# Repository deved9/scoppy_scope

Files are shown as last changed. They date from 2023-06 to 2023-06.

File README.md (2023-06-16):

# scoppy scope

scoppy_scope is a project of mine, where i try to fit a custom small form-factor 2 channel osciloscope to a Thinkpad T430's smart card reader bay.

Project is currently in development, the frontend is tested to be fully working without the use of the range switching IC. 

This project was inspired by the [Scoppy oscilloscope and logic analyzer project](https://github.com/fhdm-dev/scoppy) which sadly only supports Android devices as of this date. 

The digital part of the project, including part of the schematic and footprints, has been taken from the [Adafruit QT Py RP2040](https://github.com/adafruit/Adafruit-QT-Py-RP2040-PCB)

As of right now, the PCB is close to finished. The main focus will be shifted to the software side of the project.

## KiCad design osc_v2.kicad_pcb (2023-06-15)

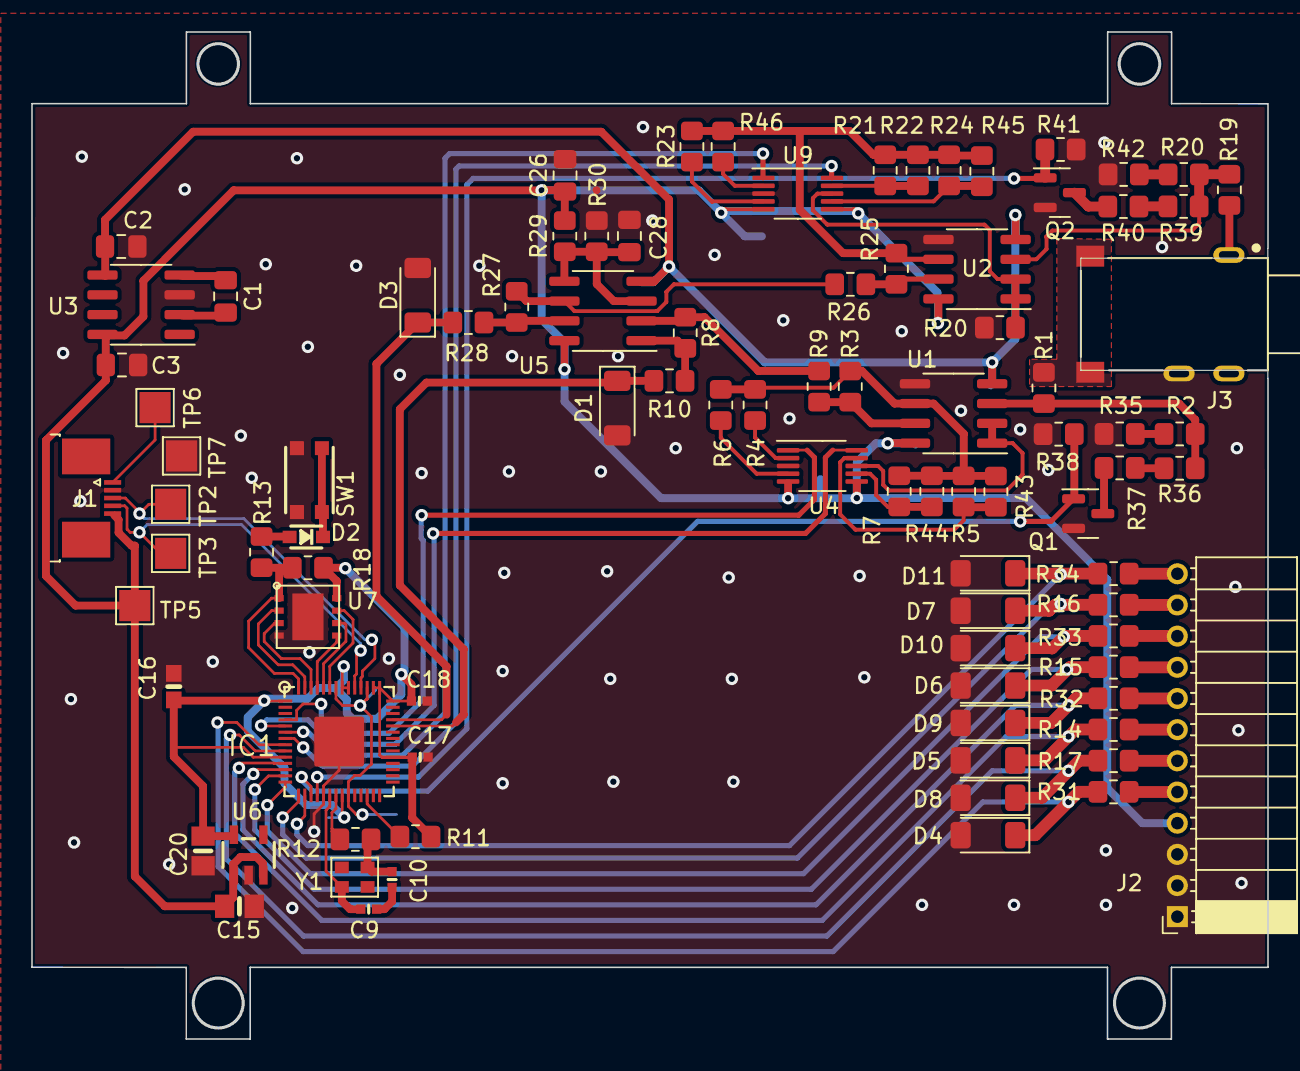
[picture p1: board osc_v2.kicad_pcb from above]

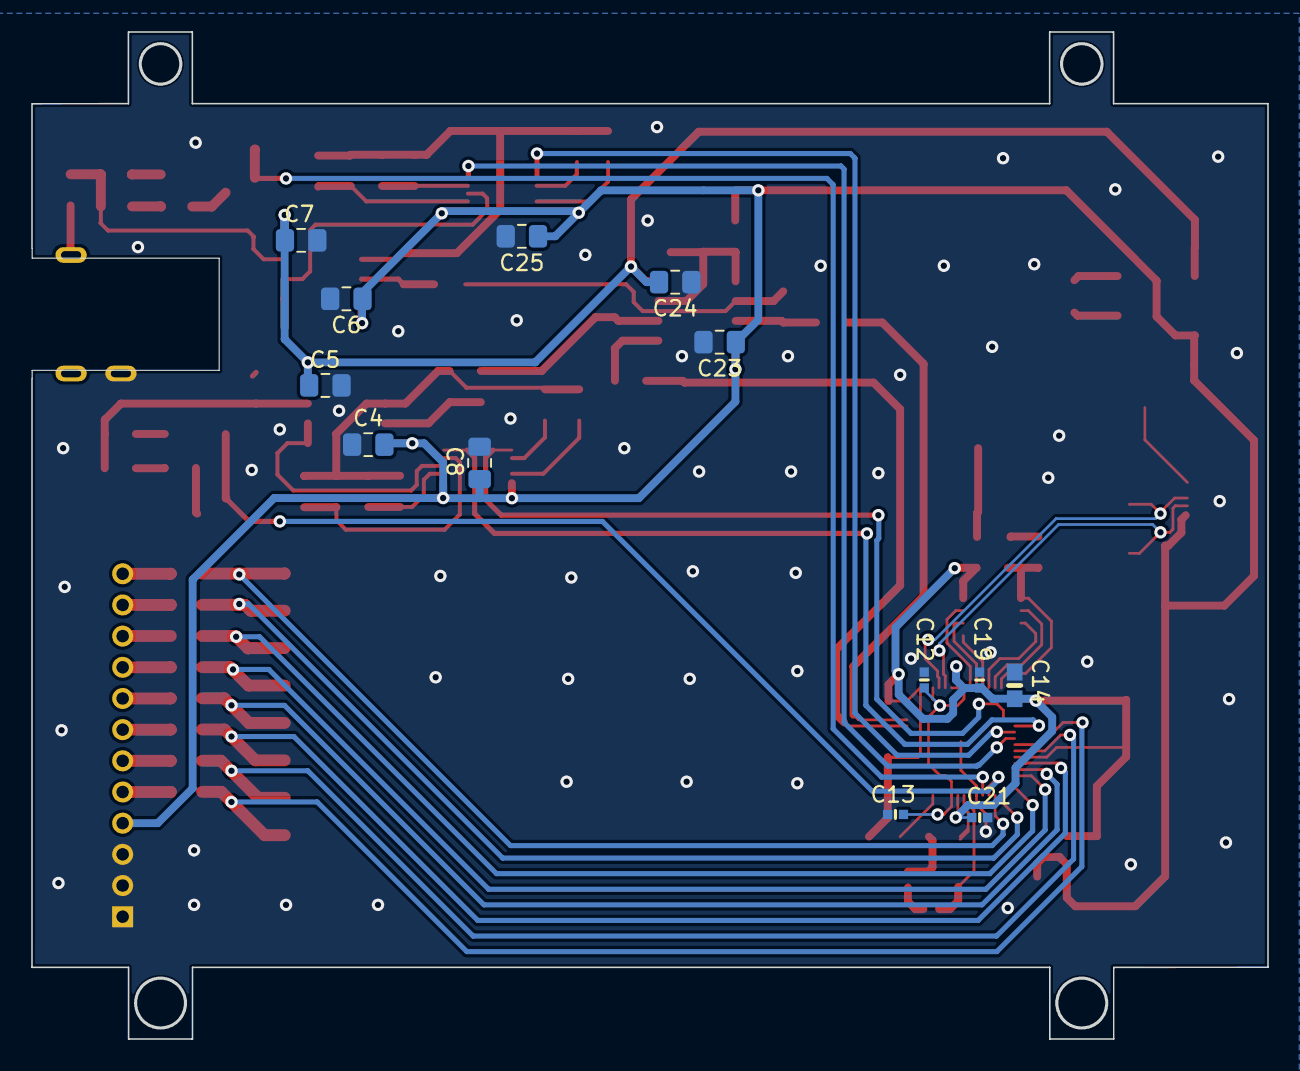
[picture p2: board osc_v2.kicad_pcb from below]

Board: 2 copper layers, 79.3 x 64.6 mm, 104 parts (13 on the bottom side), 76 nets.

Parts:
C1: 10u; C_0805_2012Metric_Pad1.18x1.45mm_HandSolder
C2, C3, C4, C5, C6, C7, C8, C23, C24, C25, C26, C28: 100u; C_0805_2012Metric_Pad1.18x1.45mm_HandSolder
C9, C10: 22pF; _0402NO
C12, C13, C17, C18, C19, C21: 0.1uF; _0402NO
C14, C16: 1uF; 0603-NO
C15, C20: 10uF; 0805-NO
D1, D3, D4, D5, D6, D7, D8, D9, D10, D11: BZV55B3V3; D_MiniMELF
D2: NSR0320; SOD-323_MINI
IC1: RP2040_QFN56; QFN56_7MM_REDUCEDEPAD
J1: Conn_01x05; TE_0-1734839-5_1x05-1MP_P0.5mm_Horizontal
J2: Conn_01x12; PinSocket_1x12_P2.00mm_Horizontal
J3: SJ-3501-SMT; CUI_SJ-3501-SMT
Q1, Q2: BSN20; SOT-23
R1, R19: 1M; R_0805_2012Metric_Pad1.20x1.40mm_HandSolder
R2, R3, R8, R9, R20, R25, R26, R27, R35, R42: 100k; R_0805_2012Metric_Pad1.20x1.40mm_HandSolder
R4, R36, R39, R46: 1k; R_0805_2012Metric_Pad1.20x1.40mm_HandSolder
R5, R21: 5k6; R_0805_2012Metric_Pad1.20x1.40mm_HandSolder
R6, R23: 10k; R_0805_2012Metric_Pad1.20x1.40mm_HandSolder
R7, R24: 56k; R_0805_2012Metric_Pad1.20x1.40mm_HandSolder
R10, R14, R15, R16, R17, R28, R31, R32, R33, R34: 100R; R_0805_2012Metric_Pad1.20x1.40mm_HandSolder
R11, R18: 10K; R_0805_2012Metric_Pad1.20x1.40mm_HandSolder
R12, R13: 1K; R_0805_2012Metric_Pad1.20x1.40mm_HandSolder
R20#2: 197k; R_0805_2012Metric_Pad1.20x1.40mm_HandSolder
R22, R43: 47k; R_0805_2012Metric_Pad1.20x1.40mm_HandSolder
R29: 9k1; R_0805_2012Metric_Pad1.20x1.40mm_HandSolder
R30: 1k8; R_0805_2012Metric_Pad1.20x1.40mm_HandSolder
R37, R40: 680R; R_0805_2012Metric_Pad1.20x1.40mm_HandSolder
R38, R41: 330R; R_0805_2012Metric_Pad1.20x1.40mm_HandSolder
R44, R45: 470k; R_0805_2012Metric_Pad1.20x1.40mm_HandSolder
SW1: KMR2; BTN_KMR2_4.6X2.8
TP2: D-; TestPoint_Pad_2.0x2.0mm
TP3: D+; TestPoint_Pad_2.0x2.0mm
TP5: 5V; TestPoint_Pad_2.0x2.0mm
TP6: SC_DETECT; TestPoint_Pad_2.0x2.0mm
TP7: GND; TestPoint_Pad_2.0x2.0mm
U1, U2, U5: LM358; SOIC-8_3.9x4.9mm_P1.27mm
U3: ICL7660; SOIC-8_3.9x4.9mm_P1.27mm
U4, U9: VSSOP-10_3x3mm_P0.5mm
U6: AP2112K-3.3; SOT23-5
U7: 8MB QSPI Flash; USON8_4X4
Y1: 12MHZ; CRYSTAL_2.5X2

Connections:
1.2V: C12.2, C13.2, IC1.23 (DVDD), IC1.45 (VREG_VOUT), IC1.50 (DVDD)
+3V3: C14.1, C16.1, C17.1, C18.1, C19.1, C20.1, C21.1, IC1.1 (IOVDD), IC1.10 (IOVDD), IC1.22 (IOVDD), IC1.33 (IOVDD), IC1.42 (IOVDD), IC1.43 (ADC_IOVDD), IC1.44 (VREG_IOVDD), IC1.48 (USB_IOVDD), IC1.49 (IOVDD), R11.1, R18.2, U6.5 (OUT), U7.8 (VCC)
+5V: C3.1, C4.1, C6.1, C8.2, C15.1, C23.1, C25.2, C26.1, J1.5, J2.4, R29.1, TP5.1, U1.8 (V+), U2.8 (V+), U3.8 (V+), U4.5 (EN), U4.6 (VCC), U5.8 (V+), U6.1 (IN), U6.3 (EN), U9.5 (EN), U9.6 (VCC)
-5V: C2.1, C5.2, C7.2, C24.2, U1.4 (V-), U2.4 (V-), U3.5 (VOUT), U5.4 (V-)
/RP2040/D+: IC1.47 (USB_D+), J1.4, TP3.1
/RP2040/D-: IC1.46 (USB_D-), J1.3, TP2.1
/RP2040/QSPI_CS: IC1.56 (~QSPI_CS), R13.1, R18.1, U7.1 (SSEL)
/RP2040/QSPI_DATA[0]: IC1.53 (QSPI_SD0), U7.5 (MOSI)
/RP2040/QSPI_DATA[1]: IC1.55 (QSPI_SD1), U7.2 (MISO)
/RP2040/QSPI_DATA[2]: IC1.54 (QSPI_SD2), U7.3 (WP#/IO2)
/RP2040/QSPI_DATA[3]: IC1.51 (QSPI_SD3), U7.7 (HOLD#/IO3)
/RP2040/QSPI_SCK: IC1.52 (QSPI_SCLK), U7.6 (SCK)
/RP2040/~RESET: IC1.26 (/RUN), R11.2
CH1: D1.1 (K), IC1.38 (GPIO26/AD0), R10.2
CH1_RANGE0: IC1.4 (GPIO2), U4.1 (A0)
CH1_RANGE1: IC1.5 (GPIO3), U4.10 (A1)
CH1_RANGE2: IC1.17 (GPIO14), Q1.1 (G), R38.1
CH1_RAW: J3.2, J3.4, R1.1
CH2: D3.1 (K), IC1.39 (GPIO27/AD1), R28.2
CH2_RANGE0: IC1.6 (GPIO4), U9.1 (A0)
CH2_RANGE1: IC1.7 (GPIO5), U9.10 (A1)
CH2_RANGE2: IC1.18 (GPIO15), Q2.1 (G), R41.1
CH2_RAW: J3.1, J3.5, R19.1
DC_OFFSET: C28.1, R29.2, R30.2, U5.3 (+), U5.5 (+)
GND: C2.2, C3.2, C4.2, C5.1, C6.2, C7.1, C8.1, C12.1, C13.1, C14.2, C15.2, C16.2, C17.2, C18.2, C19.2, C20.2, C21.2, C23.2, C24.1, C25.1, C26.2, C28.2, D1.2 (A), D3.2 (A), D4.2 (A), D5.2 (A), D6.2 (A), D7.2 (A), D8.2 (A), D9.2 (A), D10.2 (A), D11.2 (A), IC1.19 (TESTEN), IC1.P$1 (GND), J1.2, J2.1, J2.2, J2.3, J3.3, Q1.2 (S), Q2.2 (S), R20#2.2, R30.1, R35.2, R38.2, R41.2, R42.2, SW1.B (S), SW1.B' (S1), TP7.1, U1.5 (+), U2.5 (+), U3.3 (GND), U4.3 (GND), U6.2 (GND), U7.4 (VSS), U7.PAD (VSS), U9.3 (GND)
LA0: D4.1 (K), IC1.8 (GPIO6), R31.2
LA0_I: J2.5, R31.1
LA1: D8.1 (K), IC1.9 (GPIO7), R17.2
LA1_I: J2.6, R17.1
LA2: D5.1 (K), IC1.11 (GPIO8), R14.2
LA2_I: J2.7, R14.1
LA3: D9.1 (K), IC1.12 (GPIO9), R32.2
LA3_I: J2.8, R32.1
LA4: D6.1 (K), IC1.13 (GPIO10), R15.2
LA4_I: J2.9, R15.1
LA5: D10.1 (K), IC1.14 (GPIO11), R33.2
LA5_I: J2.10, R33.1
LA6: D7.1 (K), IC1.15 (GPIO12), R16.2
LA6_I: J2.11, R16.1
LA7: D11.1 (K), IC1.16 (GPIO13), R34.2
LA7_I: J2.12, R34.1
unnamed: C9.1, C10.1
unnamed: C10.2, R12.1, Y1.1
unnamed: D2.A, R13.2
unnamed: C9.2, IC1.20 (XIN), Y1.3 (2)
unnamed: IC1.21 (XOUT), R12.2
unnamed: J1.1, TP6.1
unnamed: Q1.3 (D), R37.2
unnamed: Q2.3 (D), R40.2
unnamed: R2.2, R35.1
unnamed: R3.2, R9.1, U1.7
unnamed: R8.2, R10.1, U5.1
unnamed: R20.2, R42.1
unnamed: R25.2, R26.1, U2.7
unnamed: R27.2, R28.1, U5.7
unnamed: R36.2, R37.1
unnamed: R39.2, R40.1
unnamed: D2.C, SW1.A, SW1.A' (P1)
unnamed: R1.2, R2.1, R36.1, U1.3 (+)
unnamed: U1.1, U1.2 (-), U4.8 (D1)
unnamed: R3.1, R4.2, R5.2, R6.2, R7.2, R43.2, R44.2, U1.6 (-)
unnamed: R19.2, R20.1, R39.1, U2.3 (+)
unnamed: R20#2.1, U2.1, U2.2 (-), U9.8 (D1)
unnamed: R21.2, R22.2, R23.2, R24.2, R25.1, R45.2, R46.2, U2.6 (-)
unnamed: C1.1, U3.2 (CAP+)
unnamed: C1.2, U3.4 (CAP-)
unnamed: R4.1, U4.2 (S1)
unnamed: R5.1, R43.1, U4.9 (S2)
unnamed: R6.1, U4.4 (S3)
unnamed: R7.1, R44.1, U4.7 (S4)
unnamed: R8.1, R9.2, U5.2 (-)
unnamed: R26.2, R27.1, U5.6 (-)
unnamed: R46.1, U9.2 (S1)
unnamed: R21.1, R22.1, U9.9 (S2)
unnamed: R23.1, U9.4 (S3)
unnamed: R24.1, R45.1, U9.7 (S4)
